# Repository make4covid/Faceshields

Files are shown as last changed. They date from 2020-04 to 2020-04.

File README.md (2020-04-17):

# Fork
This is the Make4Covid fork of the Charlotte MEDI's fork of Prusa's face shield.

* https://www.make4covid.co/

* https://www.charlottemedi.org/

* https://www.prusaprinters.org/prints/25857-prusa-protective-face-shield-rc3

In particular, Make4Covid is looking at injection molding `Headband.STEP` with
Texlon Plastics Corporation in North Carolina.

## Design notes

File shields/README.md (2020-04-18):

# Shields
The subdir contains various shields use, or considered for use
by Make4Covid.

* Charlotte-MEDI -- This is used by North Carolina group using mold with Texlon.
* FormTight -- This is the file used by FormTight to make their die.
* make4covid -- These are the files available on the Make4Covid website.
this is not the authoritative location for them.

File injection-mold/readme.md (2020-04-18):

This contains all of the design files for the injection molded face shields.

We want to help as many people produce face shields as possible so we’re making all of our files open source and available to everyone.

We started with the Prusa RC2 design and modified it to be injection molding friendly. With the help of Caro-Polymers, we designed a new bottom support that would accommodate PETG sheets of various thicknesses instead of being limited to only 0.02″ thick PETG.

Our design has been validated by doctors and other Health Care Workers in Charlotte, NC using the following materials to manufacture the face shields:

Following materials are used in this design: </br>
Injection molding: FDA approved Polypropylene </br>
PETG sheet: 0.02″ thick PETG (Our feedback from HCWs recommended 0.02″ thick)

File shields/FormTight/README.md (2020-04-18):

This is the file that was sent to FormTight to make a die.

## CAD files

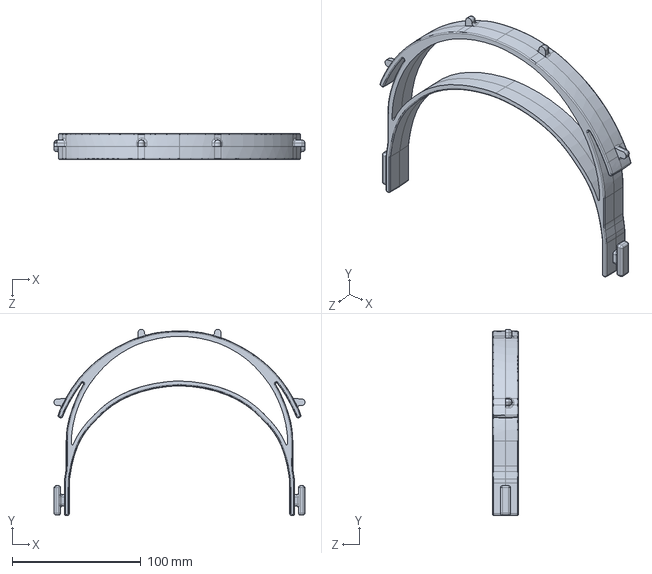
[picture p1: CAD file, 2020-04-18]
injection-mold/Headband.STEP
195.3 x 145.0 x 20.0 mm

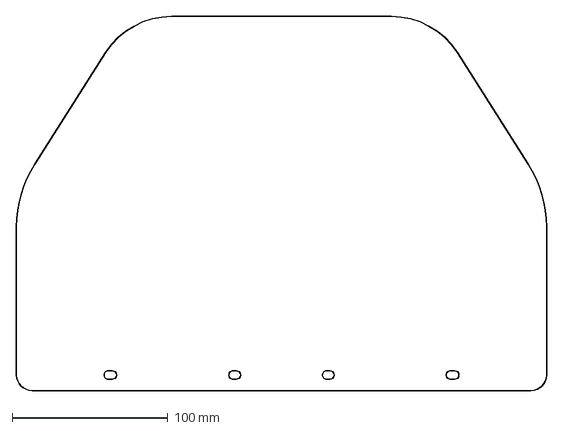
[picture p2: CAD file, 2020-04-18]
shields/FormTight/COVID shield v3 0.03in single row holes 240mm tall.dxf
340.0 x 240.0 mm

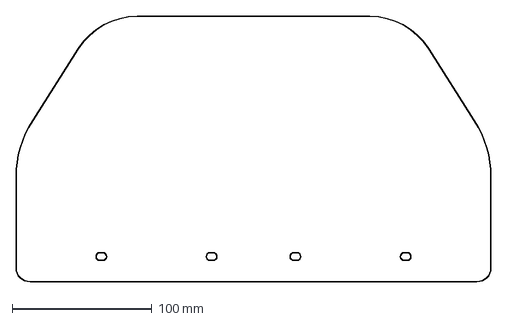
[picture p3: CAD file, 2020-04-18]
shields/make4covid/COVID shield single row holes 190mm tall reduced taper.DXF
340.0 x 190.0 mm

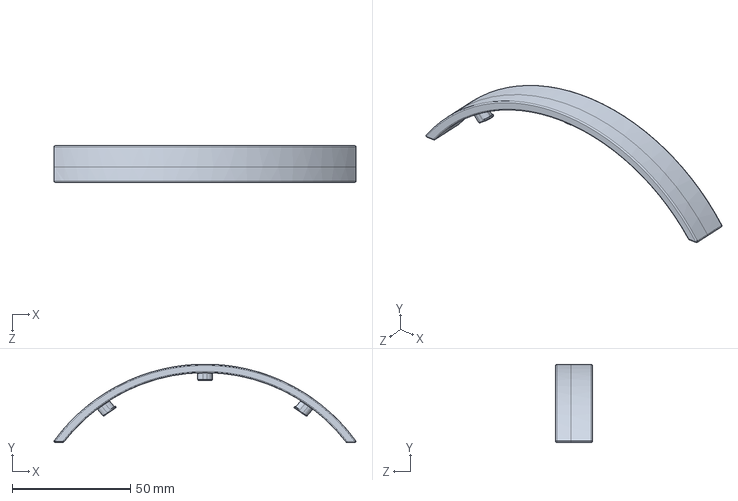
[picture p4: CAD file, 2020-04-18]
injection-mold/Bottom support bar.SLDPRT
127.9 x 33.2 x 15.5 mm

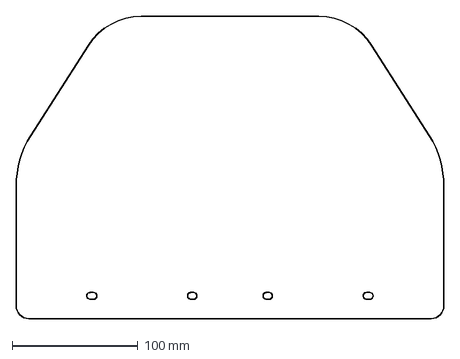
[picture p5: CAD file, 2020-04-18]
shields/make4covid/Long Shield 4_12_20.dxf
340.0 x 240.0 mm

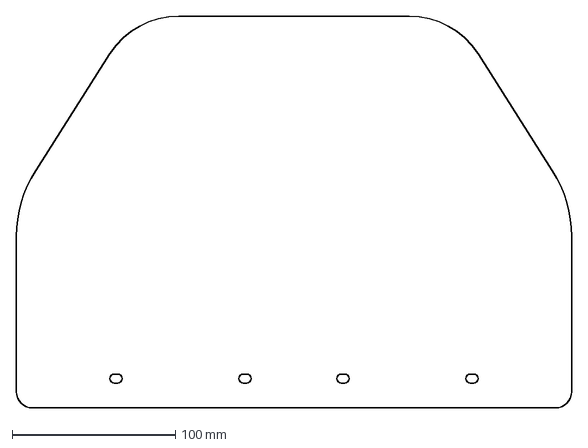
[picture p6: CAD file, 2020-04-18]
shields/make4covid/COVID shield single row holes 240mm tall.DXF
340.0 x 240.0 mm

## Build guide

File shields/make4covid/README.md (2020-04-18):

These are DXFs posted to public website.
This archive is not the authoritative source, just for tracking.

* https://sites.google.com/make4covid.co/startmaking-wip/laser-cutter

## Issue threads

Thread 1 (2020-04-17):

M4C Shield holes don't line up with IM headband

forksand, 2020-04-17:
The holes in the M4C face shields don't identically line up with the pegs in the injection molded version.

forksand, 2020-04-17:
Text copied from PDF by Andrew and Schuyler.

TEXLON Injection Molded Prusa Style Band:

Since the peg doesn’t have a radius on the both sides it doesn’t let the inner two slots sit in the
right position

Which causes the outer slot to not reach the peg.

So I widened the outer slot (a bit too much) to get it to fit. Below are two shields stacked on top
of each other to show the original slot and the one I modified.

(pics out of order)
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

Hardikclt, 2020-04-17:
we fixed this issue with this file: https://github.com/Charlotte-MEDI/Faceshields/blob/master/injection%20mold/Clear%20PETG%20Cut%20file%20(2x3).svg

If you're laser cutting the PETG which it looks like you are, it should be pretty easy to just load up that file and cut.

forksand, 2020-04-17:
Ok, but we have some thousands of shields which may not match.

forksand, 2020-04-17:
Sofia says she was able to get it to work with the 0.010", but not with 0.020", 0.30", 0.040".

forksand, 2020-04-17:
@Hardikclt Do you know which file made the SVG? I'd like to compare a single DXF with our files and Prusa's. Thx!

Hardikclt, 2020-04-18:
I think it was done in corel draw but I'm not 100% sure. Any vector drawing
program should be able to open it. If not let me know and I can get you a
different file format.

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

andrew-j-henderson, 2020-04-18:
Here's a direct comparison. The square hole on the left side extend 3.3mm wider than our most recent designs
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

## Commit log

2020-04-17 Remove files upstream uses, but Make4Covid doesn't
    [FaceShieldExtended.dxf, Face_Shield.dwg, Face_Shield.dxf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]
2020-04-18 Add file for FormTight DXF
    [COVID shield v3 0.03in single row holes 240mm tall.dxf]
2020-04-18 Shields currently on Make4Covid public site
    [COVID shield single row holes 190mm tall reduced taper.DXF, COVID shield single row holes 240mm tall.DXF, Long Shield 4_12_20.dxf]
2020-04-18 Move shields all to one subdir
    [Bottom support bar.SLDPRT, Headband.STEP]
